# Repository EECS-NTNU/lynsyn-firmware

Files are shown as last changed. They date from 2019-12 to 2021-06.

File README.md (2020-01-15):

# Lynsyn

Lynsyn is a device designed to perform application power profiling of ARM Cortex A based systems.  For more information, see the [Lynsyn firmware wiki](https://github.com/EECS-NTNU/lynsyn-firmware/wiki) and the [Lynsyn host software wiki](https://github.com/EECS-NTNU/lynsyn-host-software/wiki).

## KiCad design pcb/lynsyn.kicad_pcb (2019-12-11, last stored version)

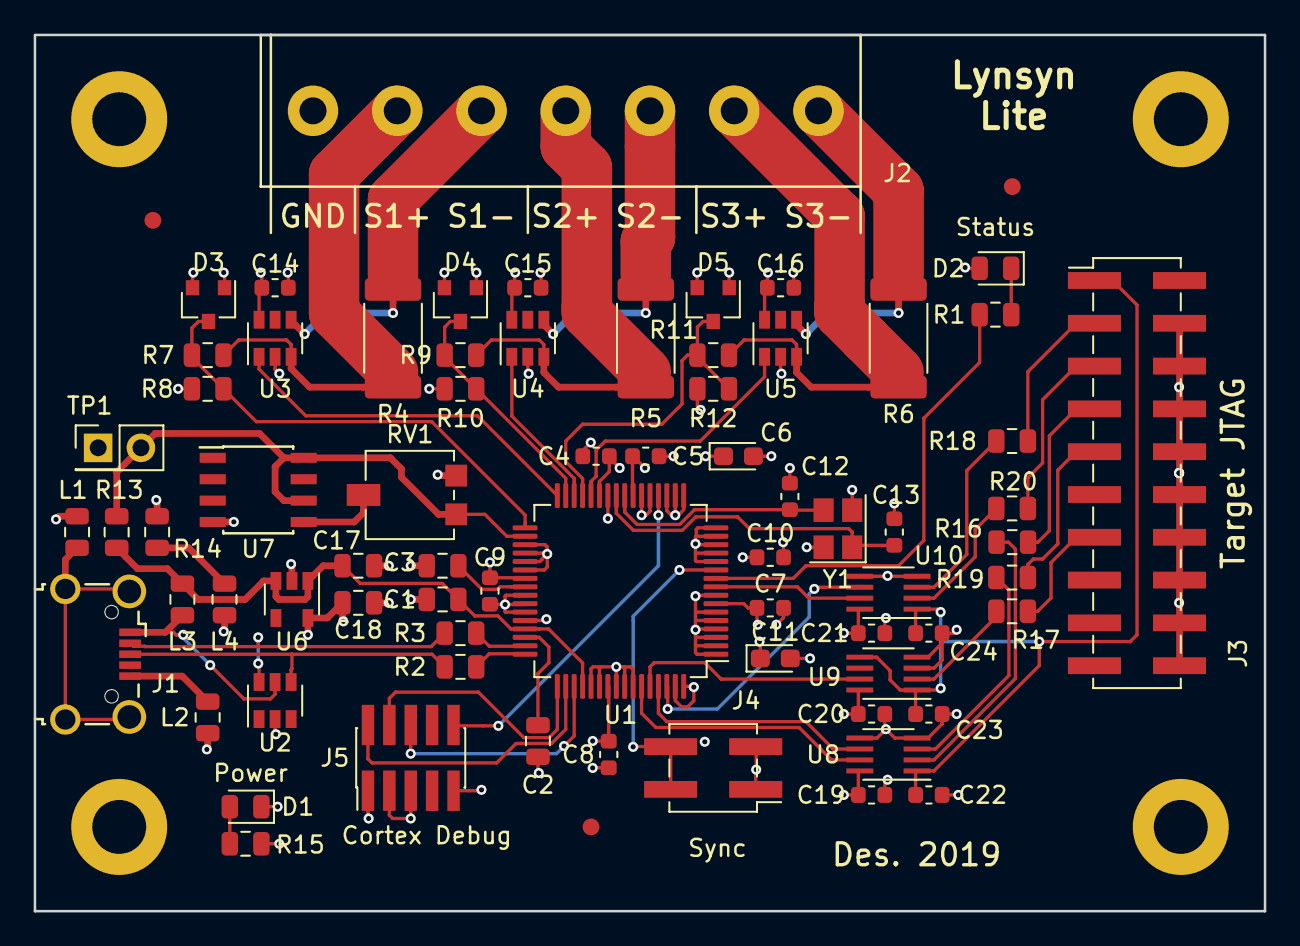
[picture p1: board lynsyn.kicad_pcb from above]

Board: 4 copper layers, 73.0 x 52.0 mm, 71 parts (0 on the bottom side), 54 nets.

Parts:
C1: 4.7u; C_0805_2012Metric
C2, C3, C17, C18: 1u; C_0805_2012Metric
C4, C5, C7, C8, C9, C10, C14, C15, C16, C19, C20, C21, C22, C23, C24: 100n; C_0603_1608Metric
C6, C11: 10u; CP_EIA-2012-12_Kemet-R
C12, C13: 12p; C_0603_1608Metric
D1: Red; LED_0805_2012Metric
D2: Green; LED_0805_2012Metric
D3, D4, D5: BAT54S; SOT-23
J1: USB Micro-B; USB_Micro-B_Wuerth_629105150521_CircularHoles
J2: power_sensor; TERMINAL_BLOCK_5mm
J3: Conn_ARM_JTAG_SWD_20; PinHeader_2x10_P2.54mm_Vertical_SMD
J4: Sync; PinHeader_2x02_P2.54mm_Vertical_SMD
J5: Cortex Debug; PinHeader_2x05_P1.27mm_Vertical_SMD
L1, L2, L3, L4: Ferrite_Bead; L_0805_2012Metric
R1, R15: 91; R_0805_2012Metric
R2, R3: 15; R_0805_2012Metric
R4, R5, R6: Rs; R_2512_6332Metric
R7, R9, R11: 82k; R_0805_2012Metric
R8, R10, R12: 10k; R_0805_2012Metric
R13: 3.6k; R_0805_2012Metric
R14: 1; R_0805_2012Metric
R16, R17, R18, R19, R20: 100; R_0805_2012Metric
RV1: 10k; Potentiometer_Vishay_TS53YL_Vertical
TP1: TEST; PinHeader_2x01_P2.54mm_Vertical
U1: EFM32GG332F1024; TQFP-64_10x10mm_P0.5mm
U2: IP4220CZ6; SOT-23-6
U3, U4, U5: LMP8640; SOT-23-6
U6: MIC5504-3.3YM5; SOT-23-5
U7: LT1009; SOIC-8_3.9x4.9mm_P1.27mm
U8, U9, U10: 74LVC2T45; SSOP-8_2.95x2.8mm_P0.65mm
Y1: 48MHz; Crystal_SMD_3225-4Pin_3.2x2.5mm

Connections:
+3.3VA: C4.1, C5.1, C6.1, C14.1, C15.1, C16.1, D3.2, D4.2, D5.2, R14.1, U1.23, U1.27, U3.6, U4.6, U5.6
+3V3: C7.1, C8.1, C9.1, C10.1, C11.1, C18.1, C19.1, C20.1, C21.1, D2.2, J5.1, L4.2, R15.1, U1.7, U1.26, U1.39, U1.55, U6.5, U8.8, U9.8, U10.8
/Current monitor/ADC0: U1.28, U5.1
/Current monitor/ADC1: D5.3, R11.2, R12.1, U1.29
/Current monitor/ADC2: U1.30, U4.1
/Current monitor/ADC3: D4.3, R9.2, R10.1, U1.31
/Current monitor/ADC4: U1.32, U3.1
/Current monitor/ADC5: D3.3, R7.2, R8.1, U1.33
/JTAG/JTAG_out_VREF: C22.1, C23.1, C24.1, J3.1, U8.1, U9.1, U9.5, U10.1
/MCU/CLK0: U1.61, U8.6
/MCU/MCU_D+: R2.1, U1.48
/MCU/MCU_D-: R3.1, U1.47
/MCU/RX0: U1.60, U9.7
/MCU/SRST: U1.62, U10.6
/MCU/TX0: U1.59, U8.7
/MCU/TX1: U1.9, U10.7
/MCU/USB_D+: J1.3, R2.2, U2.4
/MCU/USB_D-: J1.2, R3.2, U2.6
AREF: R13.2, RV1.3, TP1.2, U1.34, U7.6, U7.8
GND: C1.2, C2.2, C3.2, C4.2, C5.2, C6.2, C7.2, C8.2, C9.2, C10.2, C11.2, C12.2, C13.2, C14.2, C15.2, C16.2, C17.2, C18.2, C19.2, C20.2, C21.2, C22.2, C23.2, C24.2, D1.1, D3.1, D4.1, D5.1, J2.1, J3.4, J3.6, J3.8, J3.10, J3.12, J3.14, J3.16, J3.18, J3.20, J4.1, J4.3, J5.3, J5.5, J5.9, L1.2, L2.2, R8.2, R10.2, R12.2, RV1.1, TP1.1, U1.1, U1.2, U1.3, U1.4, U1.5, U1.6, U1.8, U1.12, U1.13, U1.14, U1.15, U1.16, U1.17, U1.18, U1.19, U1.21, U1.22, U1.35, U1.36, U1.37, U1.38, U1.41, U1.42, U1.43, U1.44, U1.53, U1.54, U1.56, U1.57, U1.58, U1.63, U1.64, U2.2, U3.2, U4.2, U5.2, U6.2, U7.4, U8.4, U8.5, U9.3, U9.4, U10.4, U10.5, Y1.2, Y1.4
unnamed: C2.1, U1.46
unnamed: C3.1, U1.40
unnamed: C12.1, U1.24, Y1.3
unnamed: C13.1, U1.25, Y1.1
unnamed: D1.2, R15.2
unnamed: D2.1, R1.2
unnamed: J1.1, L3.2, U2.5
unnamed: J1.5, L2.1
unnamed: J1.6, L1.1
unnamed: J2.2, R4.1, R7.1, U3.3
unnamed: J2.3, R4.2, U3.4
unnamed: J2.4, R5.1, R9.1, U4.3
unnamed: J2.5, R5.2, U4.4
unnamed: J2.6, R6.1, R11.1, U5.3
unnamed: J2.7, R6.2, U5.4
unnamed: J3.3, R18.2
unnamed: J3.5, R20.2
unnamed: J3.7, R16.2
unnamed: J3.9, R19.2
unnamed: J3.13, R17.2
unnamed: J4.2, J4.4, U1.11
unnamed: J5.2, U1.50
unnamed: J5.4, U1.49
unnamed: J5.6, U1.51
unnamed: J5.10, U1.20
unnamed: L4.1, R14.2
unnamed: R1.1, U1.10
unnamed: R16.1, U8.2
unnamed: R17.1, U9.2
unnamed: R18.1, U10.3
unnamed: R19.1, U8.3
unnamed: R20.1, U10.2
unnamed: RV1.2, U7.5
USB_VBUS: C1.1, C17.1, L3.1, R13.1, U1.45, U1.52, U6.1, U6.3

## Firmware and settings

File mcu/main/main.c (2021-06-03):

/******************************************************************************
 *
 *  This file is part of the Lynsyn PMU firmware.
 *
 *  Copyright 2018-2019 Asbjørn Djupdal, NTNU
 *
 *****************************************************************************/

#include "lynsyn_main.h"

#include <string.h>
#include <stdio.h>
#include <stdarg.h>
#include <inttypes.h>

#include <em_device.h>
#include <em_chip.h>
#include <em_cmu.h>
#include <em_gpio.h>
#include <em_emu.h>

#include "../common/swo.h"
#include "../common/usbprotocol.h"

#include "arm.h"
#include "jtag_lowlevel.h"
#include "adc.h"
#include "config.h"
#include "usb.h"
#include "jtag.h"
#ifdef VERSION2
#include "fpga.h"
#endif

volatile bool sampleMode;
volatile bool samplePc;
volatile bool useStopBp;
volatile int64_t sampleStop;

volatile uint32_t lastLowWord = 0;
volatile uint32_t highWord = 0;

static struct SampleReplyPacket sampleBuf1[MAX_SAMPLES] __attribute__((__aligned__(4)));
static struct SampleReplyPacket sampleBuf2[MAX_SAMPLES] __attribute__((__aligned__(4)));

static int16_t continuousCurrent[CHANNELS];
uint64_t continuousCurrentAcc[CHANNELS];
int continuousSamplesSinceLast[CHANNELS];
int16_t continuousCurrentInstant[CHANNELS];
int16_t continuousCurrentAvg[CHANNELS];

///////////////////////////////////////////////////////////////////////////////

void panic(const char *fmt, ...) {
  va_list args;
  va_start(args, fmt);
  printf("\nPanic: ");
  vprintf(fmt, args);
  printf("\n");
  va_end(args);
  while(true);
}

///////////////////////////////////////////////////////////////////////////////

int main(void) {
  sampleMode = false;

#ifndef __linux__
  // setup clocks
  CMU_ClockEnable(cmuClock_HFPER, true);
  CMU_ClockEnable(cmuClock_USB, true);
  CMU_ClockEnable(cmuClock_ADC0, true);
#endif

  printf("Lynsyn initializing...\n");

#ifndef __linux__
  // Enable cycle counter
  CoreDebug->DEMCR |= CoreDebug_DEMCR_TRCENA_Msk;
  DWT->CTRL |= 0x01;
  DWT->CYCCNT = 0;
#endif

  configInit();

  printf("Hardware V%" PRIx32 ".%" PRIx32 " Firmware %s\n", (getUint32("hwver") & 0xf0) >> 4, getUint32("hwver") & 0xf, SW_VERSION_STRING);

  jtagInitLowLevel();
  adcInit();
  usbInit();

  clearLed(0);

  printf("Ready.\n");

  int samples = 0;

  unsigned currentSample = 0;

  struct SampleReplyPacket *sampleBuf = sampleBuf1;

  // main loop
  while(true) {
#ifdef __linux__
    linux_processUsb();
#endif

    if(sampleMode) {
      int64_t currentTime = calculateTime();

      struct SampleReplyPacket *samplePtr = &sampleBuf[currentSample];

      samplePtr->flags = 0;

      bool halted = false;
      bool sampleOk = true;

      {
        samplePtr->time = currentTime;
        adcScan(samplePtr->channel);
        if(samplePc) {
          sampleOk = coreReadPcsrFast(samplePtr->pc, &halted);
          if(!sampleOk) halted = false;
          if(sampleOk && halted) {
            for(int i = 0; i < numCores; i++) {
              uint64_t pc;
              if(!readPc(i, &pc)) {
                printf("Warning, can't read PC\n");
              }
              if(pc == markBp) {
                clearBp(MARK_BP);
                coresResume();
                halted = false;
                samplePtr->flags = SAMPLE_REPLY_FLAG_MARK;
                setBp(MARK_BP, markBp);
                break;
              }
            }
          }
        } else {
          for(int i = 0; i < 4; i++) {
            samplePtr->pc[i] = 0;
          }
        }

        if(!useStopBp) {
          halted = currentTime >= sampleStop;
        }

        adcScanWait();
      }

      if(halted) {
        samplePtr->time = -1;
        sampleMode = false;
        sampleOk = true;

        if(useStopBp) {
          clearBp(STOP_BP);
          coresResume();
        }

#ifdef VERSION2
        jtagExt();
#endif
        clearLed(0);

        printf("Exiting sample mode, %d samples\n", samples);

        samples = 0;
      }

      {
        if(sampleOk) {
          samples++;
          currentSample++;

          if(samplePtr->flags & SAMPLE_REPLY_FLAG_MARK) samplePtr->pc[0] = calculateTime();

          if((currentSample >= MAX_SAMPLES) || halted) {
            sendSamples(sampleBuf, currentSample);
            if(sampleBuf == sampleBuf1) sampleBuf = sampleBuf2;
            else sampleBuf = sampleBuf1;
            currentSample = 0;
          }
        }
      }
    } else {
#ifndef __linux__
      __disable_irq();
#endif

      adcScan(continuousCurrent);
      adcScanWait();

      for(int i = 0; i < CHANNELS; i++) {
        continuousCurrentAcc[i] += continuousCurrent[i];
        continuousSamplesSinceLast[i]++;
        continuousCurrentInstant[i] = continuousCurrent[i];
      }

#ifndef __linux__
      __enable_irq();
#endif
    }
  }
}

void wait(unsigned cycles) {
#ifndef __linux__
  DWT->CYCCNT = 0;
  while(DWT->CYCCNT < cycles);
#endif
}

int64_t calculateTime() {
#ifdef __linux__
  return 0;
#else
  uint32_t lowWord = DWT->CYCCNT;
  __disable_irq();
  if(lowWord < lastLowWord) highWord++;
  lastLowWord = lowWord;
  __enable_irq();
  return ((uint64_t)highWord << 32) | lowWord;
#endif
}

int _write(int fd, char *str, int len) {
#ifndef __linux__
  for (int i = 0; i < len; i++) {
    ITM_SendChar(str[i]);
  }
#endif
  return len;
}

void getCurrentAvg(int16_t *sampleBuffer) {
  for(int i = 0; i < CHANNELS; i++) {
    sampleBuffer[i] = continuousCurrentAcc[i] / continuousSamplesSinceLast[i];
    continuousCurrentAcc[i] = 0;
    continuousSamplesSinceLast[i] = 0;
  }
}

void clearLog(void) {
  logReply.buf[0] = 0;
  logReply.size = 1;
}

void addLogLine(const char *fmt, ...) {
  if(logReply.size < MAX_LOG_SIZE) {
    va_list args;
    va_start(args, fmt);
    logReply.size += vsnprintf(logReply.buf + logReply.size - 1, MAX_LOG_SIZE - logReply.size, fmt, args);
    va_end(args);
  }
}

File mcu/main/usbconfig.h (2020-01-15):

/******************************************************************************
 *
 *  This file is part of the Lynsyn PMU firmware.
 *
 *  Copyright 2018-2019 Asbjørn Djupdal, NTNU
 *
 *****************************************************************************/

#ifndef USBCONFIG_H
#define USBCONFIG_H

#define USB_DEVICE

#define NUM_EP_USED 3
#define NUM_APP_TIMERS 1

#define CDC_CTRL_INTERFACE_NO   0
#define CDC_DATA_INTERFACE_NO   1

#define CDC_EP_DATA_OUT   0x01
#define CDC_EP_DATA_IN    0x81
#define CDC_EP_NOTIFY     0x82

#define CDC_TIMER_ID              0
#define CDC_UART_TX_DMA_CHANNEL   0
#define CDC_UART_RX_DMA_CHANNEL   1
#define CDC_TX_DMA_SIGNAL         DMAREQ_UART1_TXBL
#define CDC_RX_DMA_SIGNAL         DMAREQ_UART1_RXDATAV
#define CDC_UART                  UART1
#define CDC_UART_CLOCK            cmuClock_UART1
#define CDC_UART_ROUTE            (UART_ROUTE_RXPEN | \
                                   UART_ROUTE_TXPEN | \
                                   UART_ROUTE_LOCATION_LOC2)
#define CDC_UART_TX_PORT          gpioPortB
#define CDC_UART_TX_PIN           9
#define CDC_UART_RX_PORT          gpioPortB
#define CDC_UART_RX_PIN           10
#define CDC_ENABLE_DK_UART_SWITCH() BSP_PeripheralAccess(BSP_RS232_UART, true)

#endif

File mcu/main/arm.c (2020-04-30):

/******************************************************************************
 *
 *  This file is part of the Lynsyn PMU firmware.
 *
 *  Copyright 2018-2019 Asbjørn Djupdal, NTNU
 *
 *****************************************************************************/

#include <stdio.h>
#include <string.h>

#include <em_usart.h>

#include "arm.h"
#include "jtag.h"
#include "../common/usbprotocol.h"

///////////////////////////////////////////////////////////////////////////////

static unsigned apSelMem = 0;
static bool mem64 = false;
unsigned numCores;
unsigned numEnabledCores;
struct Core cores[MAX_CORES];

///////////////////////////////////////////////////////////////////////////////

uint32_t extractWord(unsigned *pos, uint8_t *buf) {
  unsigned byte = *pos / 8;
  unsigned bit = *pos % 8;

  *pos += 32;

  switch(bit) {
    case 0: return (buf[byte+3] << 24) | (buf[byte+2] << 16) | (buf[byte+1] << 8) | buf[byte];
    case 1: return ((buf[byte+4] & 0x01) << 31) | (buf[byte+3] << 23) | (buf[byte+2] << 15) | (buf[byte+1] << 7) | (buf[byte] >> 1);
    case 2: return ((buf[byte+4] & 0x03) << 30) | (buf[byte+3] << 22) | (buf[byte+2] << 14) | (buf[byte+1] << 6) | (buf[byte] >> 2);
    case 3: return ((buf[byte+4] & 0x07) << 29) | (buf[byte+3] << 21) | (buf[byte+2] << 13) | (buf[byte+1] << 5) | (buf[byte] >> 3);
    case 4: return ((buf[byte+4] & 0x0f) << 28) | (buf[byte+3] << 20) | (buf[byte+2] << 12) | (buf[byte+1] << 4) | (buf[byte] >> 4);
    case 5: return ((buf[byte+4] & 0x1f) << 27) | (buf[byte+3] << 19) | (buf[byte+2] << 11) | (buf[byte+1] << 3) | (buf[byte] >> 5);
    case 6: return ((buf[byte+4] & 0x3f) << 26) | (buf[byte+3] << 18) | (buf[byte+2] << 10) | (buf[byte+1] << 2) | (buf[byte] >> 6);
    case 7: return ((buf[byte+4] & 0x7f) << 25) | (buf[byte+3] << 17) | (buf[byte+2] <<  9) | (buf[byte+1] << 1) | (buf[byte] >> 7);
  }

  return 0;
}

uint8_t extractAck(unsigned *pos, uint8_t *buf) {
  unsigned byte = *pos / 8;
  unsigned bit = *pos % 8;

  *pos += 3;

  switch(bit) {
    case 0:
    case 1:
    case 2:
    case 3:
    case 4:
    case 5: return (buf[byte] >> bit) & 0x7;
    case 6: return ((buf[byte+1] & 0x1) << 2) | ((buf[byte] >> 6) & 0x3);
    case 7: return ((buf[byte+1] & 0x3) << 1) | ((buf[byte] >> 7) & 0x1);
  }

  return 0;
}

///////////////////////////////////////////////////////////////////////////////
// ARM DP

static bool dpWrite(uint16_t addr, uint32_t value) {
  return jtagDpLowAccess(LOW_WRITE, addr, value, NULL);
}

static bool dpRead(uint16_t addr, uint32_t *value) {
  if(!jtagDpLowAccess(LOW_READ, addr, 0, NULL)) return false;
  return jtagDpLowAccess(LOW_READ, DP_RDBUFF, 0, value);
}

static bool dpAbort(uint32_t abort) {
  uint8_t request_buf[8];
  memset(request_buf, 0, 8);

  request_buf[4] = (abort & 0xE0000000) >> 29;
  uint32_t tmp = (abort << 3);
  request_buf[3] = (tmp & 0xFF000000) >> 24;
  request_buf[2] = (tmp & 0x00FF0000) >> 16;
  request_buf[1] = (tmp & 0x0000FF00) >> 8;
  request_buf[0] = (tmp & 0x000000FF);

  jtagWriteIr(dpIdcode, ARM_IR_ABORT);
  if(!jtagReadWriteDr(dpIdcode, request_buf, NULL, 35)) return false;

  return true;
}

static bool dpInit(void) {
  if(!dpAbort(DP_ABORT_DAPABORT)) return false;

  uint32_t ctrlstat;
  if(!dpRead(DP_CTRLSTAT, &ctrlstat)) return false;
  
  /* Write request for system and debug power up */
  if(!dpWrite(DP_CTRLSTAT,
              ctrlstat |= DP_CTRLSTAT_CSYSPWRUPREQ |
              DP_CTRLSTAT_CDBGPWRUPREQ)) {
    return false;
  }

  /* Wait for acknowledge */
  do {
    if(!dpRead(DP_CTRLSTAT, &ctrlstat)) return false;
  } while((ctrlstat & (DP_CTRLSTAT_CSYSPWRUPACK | DP_CTRLSTAT_CDBGPWRUPACK)) !=
          (DP_CTRLSTAT_CSYSPWRUPACK | DP_CTRLSTAT_CDBGPWRUPACK));

  return true;
}

///////////////////////////////////////////////////////////////////////////////
// ARM AP

static bool apWrite(unsigned apSel, uint16_t addr, uint32_t value) {
  if(!dpWrite(DP_SELECT, ((uint32_t)apSel << 24)|(addr & 0xF0))) return false;
  return dpWrite(addr, value);
}

static bool apRead(unsigned apSel, uint16_t addr, uint32_t *value) {
  if(!dpWrite(DP_SELECT, ((uint32_t)apSel << 24)|(addr & 0xF0))) return false;
  return dpRead(addr, value);
}

///////////////////////////////////////////////////////////////////////////////
// ARM AXI

/* static bool axiReadMem(uint64_t addr, uint32_t *value) { */
/*   if(!apWrite(apSelMem, AP_TAR, addr & 0xffffffff)) return false; */
/*   if(mem64) if(!apWrite(apSelMem, AP_TAR_HI, addr >> 32)) return false; */
/*   return dpRead(AP_DRW, value); */
/* } */

/* static bool axiWriteMem(uint64_t addr, uint32_t val) { */
/*   if(!apWrite(apSelMem, AP_TAR, addr & 0xffffffff)) return false; */
/*   if(mem64) if(!apWrite(apSelMem, AP_TAR_HI, addr >> 32)) return false; */
/*   return dpWrite(AP_DRW, val); */
/* } */

///////////////////////////////////////////////////////////////////////////////
// ARM Core

static bool coreWriteReg(struct Core *core, uint16_t reg, uint32_t val) {
  uint32_t addr = core->baddr + 4*reg;
  if(!apWrite(core->ap, AP_TAR, addr)) return false;
  return dpWrite(AP_DRW, val);
}

static bool coreReadReg(struct Core *core, uint16_t reg, uint32_t *value) {
  uint32_t addr = core->baddr + 4*reg;
  if(!apWrite(core->ap, AP_TAR, addr)) return false;
  return dpRead(AP_DRW, value);
}

bool coreReadStatus(unsigned core, uint8_t *value) {
  uint32_t scr;
  if(!coreReadReg(&cores[core], ARMV8A_SCR, &scr)) return false;
  *value = scr & 0x3f;
  return true;
}

bool readPc(unsigned core, uint64_t *value) {
  if(cores[core].enabled) {
    if(cores[core].type == ARMV7A) {
      uint32_t dbgdscr;

      if(!coreReadReg(&cores[0], ARMV7A_DSCR, &dbgdscr)) return false;
      dbgdscr |= DSCR_ITREN;
      if(!coreWriteReg(&cores[0], ARMV7A_DSCR, dbgdscr)) return false;

      if(!coreWriteReg(&cores[core], ARMV7A_ITR, 0xe1a0000f)) return false;
      uint32_t regno = 0;
      uint32_t instr = MCR | DTRTXint | ((regno & 0xf) << 12);
      if(!coreWriteReg(&cores[core], ARMV7A_ITR, instr)) return false;

      uint32_t dtrtx;
      if(!coreReadReg(&cores[core], ARMV7A_DTRTX, &dtrtx)) return false;
      *value = dtrtx - 8;

      return true;

    } else if(cores[core].type == ARMV8A) {
      if(!coreWriteReg(&cores[core], ARMV8A_ITR, ARMV8A_MRS_DLR(0))) return false;
      if(!coreWriteReg(&cores[core], ARMV8A_ITR, ARMV8A_MSR_GP(SYSTEM_DBG_DBGDTR_EL0, 0))) return false;

      uint32_t low;
      uint32_t high;

      if(!coreReadReg(&cores[core], ARMV8A_DTRRX, &high)) return false;
      if(!coreReadReg(&cores[core], ARMV8A_DTRTX, &low)) return false;

      *value = ((uint64_t)high << 32) | low;

      return true;
    }
  }

  return false;
}

uint64_t calcOffset(uint64_t dbgpcsr) {
  return dbgpcsr & ~3;
}
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

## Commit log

2019-12-11 Moved to new repository.
    [current.sch, jtag.sch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]
2019-12-11 Fixed silkscreen and added gerber files
    [lynsyn-B.Cu.gbr, lynsyn-B.Mask.gbr, lynsyn-B.Paste.gbr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]
2019-12-11 New calibration scheme
2019-12-11 Bugfix with lynsyn_tester and lynsyn original
    [main.c]
2019-12-12 Added number of cores and sensors to the database and csv files. GUI now only shows sensors and cores that are present.
2019-12-12 Fixed FPGA flashing to lynsyn_tester when using original boards.
    [main.c]
2019-12-13 Just updated some page information in the schematics. No change to the PCB.
    [current.sch, jtag.sch, lynsyn.sch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]
2020-01-09 Fixed compile warnings in windows. Added new Lynsyn Lite (V3.1) support to lynsyn_tester.
    [linux.c, main.c, usb.c]
2020-01-13 Reorganized repository. This is now the private one and has the firmware and pcb. The host software is moved to a public repo.
2020-01-14 Moved PCB to separate repo
    [current.sch, jtag.sch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]
2020-01-28 Moved calibration from firmware to host
2020-04-30 Added support for receiving ARM PIDR values over USB.
2021-06-03 Bugfix for version 2
    [main.c, usb.c]
